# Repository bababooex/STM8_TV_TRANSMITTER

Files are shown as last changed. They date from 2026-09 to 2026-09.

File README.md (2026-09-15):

# **STM8_TV_TRANSMITTER**
My first experiments with bare metal programming on STM8. With SPL from ST I wouldn´t be able to fit whole code in the chip. This replaces rf modulator library for STM8 that I used earlier. I also took alot of inspiration from various websites and forums, so for these have look at credits. RF modulator used accepts analog video and audio inputs and gives RF out power around 82 dBuV max on 75 ohm (2.11 µW/-26.75 dBm). RF amplifier gives the low power signal some boost (~40 dB) to get to mW range (<30 mW). With good antenna this signal should reach atleast few tenths of meters. TV channels are configured for east european analog TV standard frequencies, not american!
> [!WARNING]
> RF modulator, when amplified, breaks RF laws in some countries, like Czechia (ČTÚ limits). I´m not responsible for any interference with public services or radio stations. Analog TV signals are quite wide on the spectrum and also noisy, so be careful!
## **Default pins and connections**
- button pins are adjustable in main.c, display connections in display .header file, software i2c pins in swi2c .header file. I you want to change them, follow the proper definitions (port a as PA and pin 
 as PIN2 for example)
- RF modulator RF out to RF amp input, RF amp output to proper antenna, like uhf folded dipole to give maximum range. Or you can just connect RF modulator output directly to TV and set desired channel or frequency
## **Images**

Device running on channel 21, frequency 471.25 MHz
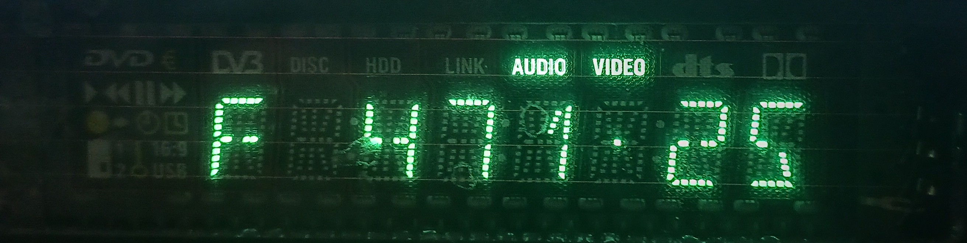
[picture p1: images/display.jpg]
display


RF amplifier - I highly recommend for UHF, because you will get most out of RF modulator. Also, on lower frequencies, there will be harmonics from dividing.
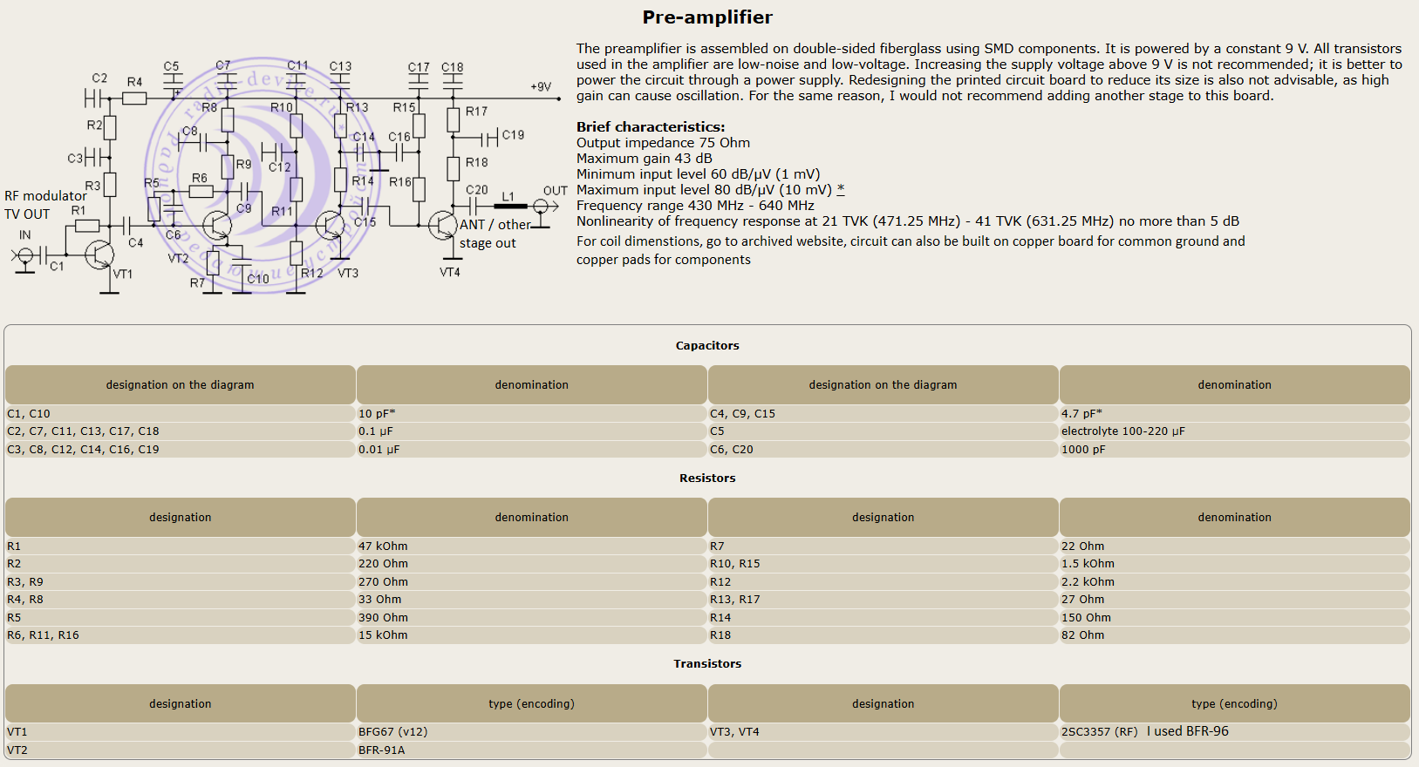
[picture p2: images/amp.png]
amplifier


Basic RF modulator circuit. Either use existing modulator or make it based off the schematic.
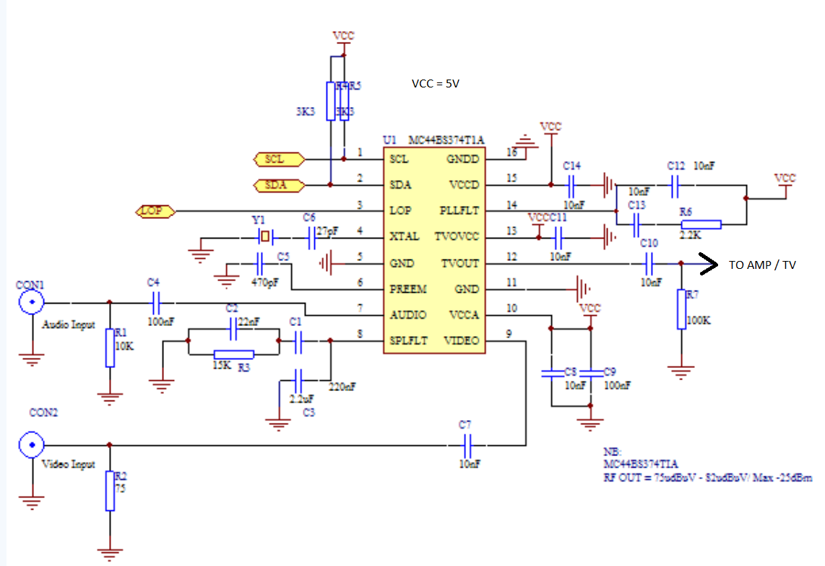
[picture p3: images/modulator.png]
modulator


## **Libraries and header files used**
- My [PT6311/PT6315](https://github.com/bababooex/STM8_PT6311_LIBRARY) library to control the VFD display
- MBS74T1AEF (MC44BS374T1) [RF modulator](https://github.com/tom2238/arduino-mc44bs374t1) library from Arduino, rewritten for STM8 compatibility with AIs help
- [Register tables](https://github.com/jukkas/stm8-sdcc-examples/blob/master/stm8.h) for stm8s103 + with some additions from me
## **Credits**
- Russian forum [VRTP.RU](https://vrtp.ru/) for project inspiration and control + software behavior, my device tries to be similar like described [here](https://vrtp.ru/index.php?act=categories&CODE=article&article=3650)
- @tom2238 for his arduino code
- @jukkas for his register table that I didn´t have to create from scratch

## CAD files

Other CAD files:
RFmod_bare_metal/rfmod_bare_metal.stp

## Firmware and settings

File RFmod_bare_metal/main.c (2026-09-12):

#include "stm8_pt6311.h"
#include "stm8s_delay.h"
#include "mbs74t1aef.h"
#include "stm8s.h"
#include "swi2c.h"

/*
 *  Software controller for MBS74T1AEF with user interface with VFD display (HL-D898W) board from sat. tuner and three buttons.
 *	UP button toggles on/off functions, or moves channel/frequency up, STATUS button changes screen view, DOWN button moves channel/frequency down. 
 *  Device uses internal EEPROM to save user data, if required, otherwise defaults to channel 21 and D/K sound system
 *
 *  tested on stm8s103f3p6 chip
 *  Created on: 12. 9. 2026
 *  Author: Adam Fucik
 *  
 */
 
//macros for buttons
#define UP_BTN_PORT  PC
#define UP_BTN_PIN   PIN4
#define STATUS_BTN_PORT   PC
#define STATUS_BTN_PIN PIN3
#define DOWN_BTN_PORT  PA
#define DOWN_BTN_PIN  PIN3
//readers
#define UP_BTN_READ()      ((PORT(UP_BTN_PORT, IDR) & UP_BTN_PIN) ? 1 : 0)
#define STATUS_BTN_READ()  ((PORT(STATUS_BTN_PORT, IDR) & STATUS_BTN_PIN) ? 1 : 0)
#define DOWN_BTN_READ()    ((PORT(DOWN_BTN_PORT, IDR) & DOWN_BTN_PIN) ? 1 : 0)
// Constants for acceleration
#define DEBOUNCE_MS         10
#define INITIAL_REPEAT_DELAY_MS  500   //autorepeat
#define INITIAL_REPEAT_INTERVAL_MS 450 // first repeat
#define MIN_REPEAT_INTERVAL_MS     5  // fastest repeat
#define ACCEL_FACTOR         4        // repeat divider
//memory start addr
#define EEPROM_START       0x4000
//freq + channel macros
#define RF_FREQ_MIN_KHZ          45000
#define RF_FREQ_MAX_KHZ         880000
#define RF_FREQ_STEP_KHZ           250
//channel frequencies in khz
#define CH21_FREQ_KHZ           471250
#define CH21_LAST_FREQ_KHZ      871250
#define CH6_FREQ_KHZ            175250
#define CH12_FREQ_KHZ           223250
#define CH3_FREQ_KHZ             77250
#define CH5_FREQ_KHZ             93250
#define CH1_FREQ_KHZ             49750
#define CH2_FREQ_KHZ             59250
//all toggleable screens in enum
typedef enum {
		frequency_state=0,
    channel_state,
		sound_state,
		ps_ratio_state,
		tpen_state,
		pwc_state,
		memory_state
} ScreenState;
//sound enum
typedef enum {
    MN_4_5MHZ = 0,
    BG_5_5MHZ,
    I_6_0MHZ,
    DK_6_5MHZ
} RFMod_sound_system;
//last memory conf enum
typedef struct {
    uint32_t frequency;
    uint8_t  ps_ratio;
    uint8_t  tpen;
    uint8_t  pwc;
    uint8_t  sound;
} Data_Memory;
//button speeder
typedef struct {
    uint8_t last_raw;         
    uint8_t stable;            
    uint8_t pressed;          
    uint32_t debounce_start;   
    uint32_t press_start;    
    uint32_t last_repeat;     
    uint16_t repeat_interval;  
} ButtonAccel;
//simple debounce eunm
typedef struct {
    uint8_t last_raw;
    uint8_t stable;
    uint32_t debounce_start;
} ButtonSimple;
//global vars
ScreenState current_screen;
RFModulator mod;
static volatile uint32_t tim4_ms_counter = 0;
//aliases for nonblocking buttons
ButtonAccel up_btn, down_btn;
ButtonSimple status_btn;
//shitter
uint8_t i;
//all data from mod defualts
uint32_t mod_frequency = 471250;
bool ps_ratio = 0;
bool tpen = 0;
bool pwc = 0;
uint8_t channel, last_channel = 21;
RFMod_sound_system sound = DK_6_5MHZ;

bool change_tracker = false;

void button_accel_init(ButtonAccel *btn);
void button_simple_init(ButtonSimple *btn);
uint8_t button_accel_check(uint8_t raw, ButtonAccel *btn);
uint8_t button_simple_check(uint8_t raw, ButtonSimple *btn);

void clock_setup(void);
void tim4_isr_setup(void);
void memory_handler(bool write);//memory saver
//screens - each matches different toggleable modulator configuration
void frequency_screen(void);
void channel_screen(void);
void sound_screen(void);
void ps_ratio_screen(void);
void tpen_screen(void);
void pwc_screen(void);
void memory_screen(void);
//st button checker
void check_st_button(void);
void btn_init(void);
//screen updater
void update_screen(void);

void freq_visuals(uint32_t frequency);
void freq_update_visuals(uint8_t move, uint16_t step_khz);
void channel_update_visuals(uint8_t move);
void channel_recalculate(uint32_t mod_frequency);
void bool_updaters(ScreenState screen);
void sound_system(RFMod_sound_system value);

@far @interrupt void timer4_isr(void)
{
    ++tim4_ms_counter; 
    TIM4_SR &= (uint8_t)(~TIM_SR1_UIF);
}

void main(void)
{
		clock_setup();//init main clock + timer
		tim4_isr_setup();//nonblocking delay
		btn_init();
		button_accel_init(&up_btn);
		button_accel_init(&down_btn);
		button_simple_init(&status_btn);
		pt6311_init(9);
		pt6311_set_display_state(PT6311_DISPLAY_ON);//prevent bugs
		for (i = 1; i < 10; i++)
		{
        pt6311_write_digit(i, 0xFFFFFF); 
				delay_ms(200);
		}
		delay_ms(300);
		pt6311_clear_display();
		pt6311_write_string(1,"TVTXV1-0 ");
		delay_ms(1200);
		pt6311_clear_display();	
		swi2c_init();
		RFModulator_Init(&mod, MC44BS374T1_ADDR);//start with defaults
		memory_handler(0); //load last data
		current_screen = frequency_state;//force current screen
		//force to display data directy to avoid errors
		pt6311_write_string(1,"F");
		freq_visuals(mod_frequency);
		while (1) {
			update_screen();
			check_st_button();
		}
}
void btn_init(void){//init three buttons as pu no it
		PORT(UP_BTN_PORT, DDR) &= ~UP_BTN_PIN;
    PORT(UP_BTN_PORT, CR1) |= UP_BTN_PIN;
    PORT(UP_BTN_PORT, CR2) &= ~UP_BTN_PIN;
		PORT(DOWN_BTN_PORT, DDR) &= ~DOWN_BTN_PIN;
    PORT(DOWN_BTN_PORT, CR1) |= DOWN_BTN_PIN;
    PORT(DOWN_BTN_PORT, CR2) &= ~DOWN_BTN_PIN;
		PORT(STATUS_BTN_PORT, DDR) &= ~STATUS_BTN_PIN;
    PORT(STATUS_BTN_PORT, CR1) |= STATUS_BTN_PIN;
    PORT(STATUS_BTN_PORT, CR2) &= ~STATUS_BTN_PIN;
}
//eeprom memory helpers
static void eeprom_unlock(void)
{
    if (!(FLASH_IAPSR & FLASH_IAPSR_DUL)) {
        FLASH_DUKR = FLASH_DUKR_KEY1;
        FLASH_DUKR = FLASH_DUKR_KEY2;

        while (!(FLASH_IAPSR & FLASH_IAPSR_DUL));
    }
}
static void eeprom_lock(void)
{
    FLASH_IAPSR &= (uint8_t)~FLASH_IAPSR_DUL;
}
static void eeprom_write_byte(uint16_t addr, uint8_t value)
{
    eeprom_unlock();

    *(volatile uint8_t *)addr = value;

    while (!(FLASH_IAPSR & FLASH_IAPSR_EOP));

    eeprom_lock();
}
static uint8_t eeprom_read_byte(uint16_t addr)
{
    return *(volatile uint8_t *)addr;
}
static void eeprom_write(uint16_t addr, const uint8_t *data, uint8_t len)
{
    uint8_t i;

    eeprom_unlock();

    for (i = 0; i < len; i++) {
        *(volatile uint8_t *)addr++ = data[i];

        while (!(FLASH_IAPSR & FLASH_IAPSR_EOP));
    }

    eeprom_lock();
}
static void eeprom_read(uint16_t addr, uint8_t *data, uint8_t len)
{
    uint8_t i;

    for (i = 0; i < len; i++) {
        data[i] = *(volatile uint8_t *)addr++;
    }
}
//memory handling
void memory_handler(bool write) {
	Data_Memory M;
	if (write){
    M.frequency = (uint32_t) mod_frequency;
    M.ps_ratio  = (bool)ps_ratio;
    M.tpen      = (bool)tpen;
    M.pwc       = (bool)pwc;
    M.sound     = (uint8_t)sound;
    eeprom_write(EEPROM_START,
                 (uint8_t *)&M,
                 sizeof(Data_Memory));
	}
	else{
    eeprom_read(EEPROM_START,
                (uint8_t *)&M,
                sizeof(Data_Memory));
		if (M.frequency < RF_FREQ_MIN_KHZ ||//some validation here
        M.frequency > RF_FREQ_MAX_KHZ ||
        M.sound > DK_6_5MHZ) {
				mod_frequency = 471250;
        ps_ratio = 0;
        tpen = 0;
        pwc = 0;
        sound = DK_6_5MHZ;
        RFModulator_SetFrequency(&mod, mod_frequency);
			}
		else{
        mod_frequency = M.frequency;
        ps_ratio = M.ps_ratio;
        tpen     = M.tpen;
        pwc      = M.pwc;
        sound    = (RFMod_sound_system)M.sound;

        RFModulator_SetFrequency(&mod, mod_frequency);
        RFModulator_SetPictureSoundRatio(&mod, ps_ratio);
        RFModulator_SetSoundSubcarrier(&mod, sound);
        RFModulator_SetPeakWhiteClip(&mod, pwc);
        RFModulator_SetTestPattern(&mod, tpen);
    } 
	}
}
static void question_writer(void){//write ?
		pt6311_write_digit(6, 0x1051);
		pt6311_write_digit(7, 0x000000);
}
//last data saver
void memory_screen(void){
	if (!change_tracker){
			pt6311_write_string(1,"SAVE ");
			question_writer();
			change_tracker=true;
		}
    if (button_accel_check(UP_BTN_READ(), &up_btn)) {
        memory_handler(1);
				//indicate
				pt6311_write_string(6,"OK");
				pt6311_write_digit(0, 128);
				delay_ms(300);
				pt6311_write_string(1,"SAVE");
				question_writer();
				pt6311_write_digit(0, 0x000000);
    } 
}
//init button speeder func
void button_accel_init(ButtonAccel *btn) {
    btn->last_raw = 1;
    btn->stable = 1;
    btn->pressed = 0;
    btn->debounce_start = 0;
    btn->press_start = 0;
    btn->last_repeat = 0;
    btn->repeat_interval = INITIAL_REPEAT_INTERVAL_MS;
}
//check speeding
uint8_t button_accel_check(uint8_t raw, ButtonAccel *btn)
{
    uint32_t now = tim4_ms_counter;

    if (raw != btn->last_raw) {
        btn->last_raw = raw;
        btn->debounce_start = now;
    }

    if ((uint32_t)(now - btn->debounce_start) >= DEBOUNCE_MS) {
        btn->stable = raw;
    }

    if (btn->stable == 0 && !btn->pressed) {
        btn->pressed = 1;
        btn->press_start = now;
        btn->last_repeat = now;
        btn->repeat_interval = INITIAL_REPEAT_INTERVAL_MS;
        return 1;
    }

    if (btn->stable == 0 && btn->pressed) {
        if ((uint32_t)(now - btn->press_start) >= INITIAL_REPEAT_DELAY_MS) {

            if ((uint32_t)(now - btn->last_repeat) >= btn->repeat_interval) {
                btn->last_repeat = now;

                if (btn->repeat_interval > MIN_REPEAT_INTERVAL_MS) {
                    btn->repeat_interval =
                        (uint16_t)((btn->repeat_interval * 8) / 10);

                    if (btn->repeat_interval < MIN_REPEAT_INTERVAL_MS) {
                        btn->repeat_interval = MIN_REPEAT_INTERVAL_MS;
                    }
                }

                return 1;
            }
        }
    }

    if (btn->stable == 1 && btn->pressed) {
        btn->pressed = 0;
    }

    return 0;
}

void button_simple_init(ButtonSimple *btn) {
    btn->last_raw = 1;
    btn->stable = 1;
    btn->debounce_start = 0;
}
uint8_t button_simple_check(uint8_t raw, ButtonSimple *btn)
{
    uint32_t now = tim4_ms_counter;

    if (raw != btn->last_raw) {
        btn->last_raw = raw;
        btn->debounce_start = now;
    }

    if ((uint32_t)(now - btn->debounce_start) >= DEBOUNCE_MS) {
        if (btn->stable != raw) {
            btn->stable = raw;

            if (btn->stable == 0) {
                return 1;
            }
        }
    }

    return 0;
}

void clock_setup(void)
	{
		CLK_CKDIVR = 0;
  }
	
void tim4_isr_setup(void) {
    TIM4_CR1 &= ~TIM_CR1_CEN;    
    TIM4_PSCR = 0x07;  
    TIM4_ARR = 124;    
		TIM4_CNTR = 0;
		TIM4_SR &= ~TIM_SR1_UIF;
    TIM4_IER |= TIM_IER_UIE;
    TIM4_CR1 |= TIM_CR1_CEN;
    enableInterrupts();
}
/*//lock indicator, because memory constraints, Im not using it
static void lock_reader(void){
	bool lock;
	lock = !((RFModulator_GetStatus(&mod) >> 0) & 1);
	if (lock){
		pt6311_write_digit(0, 8192);
	}
	else{
		pt6311_write_digit(0, 0x000000);
	}
}
*/
void check_st_button(void) {
        if (button_simple_check(STATUS_BTN_READ(), &status_btn)) {
            current_screen++;
						change_tracker=false;//track static changes, avoid refreshing not needed stuff
            if (current_screen > memory_state) {
                current_screen = frequency_state;
            }
            pt6311_clear_display();	
		}
}

void update_screen(void) {
    switch (current_screen) {
				case frequency_state:
            frequency_screen();
            break;
			
				case channel_state:
            channel_screen();
            break;
						
        case sound_state:
            sound_screen();
            break;
						
        case ps_ratio_state:
            ps_ratio_screen();
            break;
            
        case tpen_state:
            tpen_screen();
            break;
            
        case pwc_state:
            pwc_screen();
            break;
				
				case memory_state:
            memory_screen();
            break;		
						
        default:
            current_screen = frequency_state;
            break;
    }
}

void freq_visuals(uint32_t mod_frequency){//onetime frequency load
	uint16_t frec1;
	int8_t frec2;
	frec1 = (uint16_t)(mod_frequency / 1000);
	frec2 = (uint8_t)((mod_frequency % 1000) / 10);
	
	if (frec1<100){
		pt6311_write_digit(3, 0x000000);
		pt6311_write_int(4,frec1);//mhz
	}
	else{
		pt6311_write_int(3,frec1);//mhz
	}
	if (frec2==0){
		//shitty corrector
		pt6311_write_string(7,"00");//khz
	}
	else{
		pt6311_write_int(7,frec2);//khz
	}
	pt6311_write_digit(6, 0x80);//dec dot
}

void freq_update_visuals(uint8_t move, uint16_t khz_step){//frequency updater
	if (move) {
        if (mod_frequency <= (RF_FREQ_MAX_KHZ - khz_step)) {
            mod_frequency += khz_step;
        }
	} else {
        if (mod_frequency >= (RF_FREQ_MIN_KHZ + khz_step)) {
            mod_frequency -= khz_step;
        }
	}
		
	freq_visuals(mod_frequency);			
	RFModulator_SetFrequency(&mod, mod_frequency);
}

void frequency_screen(void)//up or down 250 khz
{
		if (!change_tracker){
			pt6311_write_string(1,"F");
			freq_visuals(mod_frequency);
			change_tracker=true;
		}
    if (button_accel_check(UP_BTN_READ(), &up_btn)) {
        freq_update_visuals(1, RF_FREQ_STEP_KHZ);
    } else if (button_accel_check(DOWN_BTN_READ(), &down_btn)) {
        freq_update_visuals(0, RF_FREQ_STEP_KHZ);
    }
}

void channel_update_visuals(uint8_t move){
		if (move){
			if (channel < 12) {
					channel++;
				} else if (channel == 12) {
						channel = 21;
        } else if (channel < 71) {
            channel++;
        }
		}
		else{
			if (channel > 21) {
							channel--;
        } else if (channel == 21) {
            channel = 12;
        } else if (channel > 1) {
            channel--;
        }
		}
		//recalculation from library used in here, avoids rfmodulator set channel function
		if (channel >= 21) {
        mod_frequency =
            CH21_FREQ_KHZ + ((uint32_t)(channel - 21) * 8000);
    } else if (channel >= 6) {
        mod_frequency =
            CH6_FREQ_KHZ + ((uint32_t)(channel - 6) * 8000);
    } else if (channel >= 3) {
        mod_frequency =
            CH3_FREQ_KHZ + ((uint32_t)(channel - 3) * 8000);
    } else {
        mod_frequency =
            CH1_FREQ_KHZ + ((uint32_t)(channel - 1) * 9500);
    }
		if (channel<10){
			pt6311_write_digit(7, 0x000000);
			pt6311_write_int(6, channel);
		}
		else{
			pt6311_write_int(6, channel);
		}
		RFModulator_SetFrequency(&mod, mod_frequency);
}
void channel_recalculate(uint32_t mod_frequency) {
		if (mod_frequency >= CH21_FREQ_KHZ && mod_frequency <= CH21_LAST_FREQ_KHZ) {
        channel = (uint8_t)(21 + ((mod_frequency - CH21_FREQ_KHZ) / 8000));
        if (channel > 71) {
            channel = 71;
        }
    }
    else if (mod_frequency >= CH6_FREQ_KHZ && mod_frequency <= CH12_FREQ_KHZ) {
        channel = (uint8_t)(6 + ((mod_frequency - CH6_FREQ_KHZ) / 8000));
        if (channel > 12) {
            channel = 12;
        }
    }
    else if (mod_frequency >= CH3_FREQ_KHZ && mod_frequency <= CH5_FREQ_KHZ) {
        channel = (uint8_t)(3 + ((mod_frequency - CH3_FREQ_KHZ) / 8000));
        if (channel > 5) {
            channel = 5;
        }
    }
    else if (mod_frequency >= CH1_FREQ_KHZ && mod_frequency <= CH2_FREQ_KHZ) {
        channel = (uint8_t)(1 + ((mod_frequency - CH1_FREQ_KHZ) / 9500));
        if (channel > 2) {
            channel = 2;
        }
    }
    else {
        channel = last_channel;//if user goes out of channel range display last valid
    }
		last_channel=channel;//save last valid channel matching exact frequency
    if (channel<10){
			pt6311_write_digit(7, 0x000000);
			pt6311_write_int(6, channel);
		}
		else{
			pt6311_write_int(6, channel);
		}
}
void channel_screen(void){
		if (!change_tracker){
				pt6311_write_string(1,"CHAN");
				channel_recalculate(mod_frequency);
				change_tracker=true;
		}
		if (button_accel_check(UP_BTN_READ(), &up_btn)){
					channel_update_visuals(1);
		} else if (button_accel_check(DOWN_BTN_READ(), &down_btn))  {
					channel_update_visuals(0);					
		} 
}

void bool_updaters(ScreenState screen){//bool updaters 
		if (screen == ps_ratio_state) {
			if (ps_ratio){
					pt6311_write_string(5,"16dB");
					RFModulator_SetPictureSoundRatio(&mod, MC44BS374T1_PS_16);
					pt6311_write_digit(0, 16384);
				}
				else{
					pt6311_write_string(5,"12dB");
					RFModulator_SetPictureSoundRatio(&mod, MC44BS374T1_PS_12);
					pt6311_write_digit(0, 0x000000);
				}
			
    } 
    else if (screen == tpen_state){
        if (tpen){
					pt6311_write_string(6,"ON ");
					RFModulator_SetTestPattern(&mod, MC44BS374T1_TPEN_ON);
					pt6311_write_digit(0, 64);
				}
				else{
					pt6311_write_string(6,"OFF");
					RFModulator_SetTestPattern(&mod, MC44BS374T1_TPEN_OFF);
					pt6311_write_digit(0, 0x000000);
				}
    } 
    else if (screen == pwc_state) {
			if (pwc){
					pt6311_write_string(6,"OFF");
					RFModulator_SetPeakWhiteClip(&mod, MC44BS374T1_PWC_OFF);
					pt6311_write_digit(0, 1024);
				}
				else{
					pt6311_write_string(6,"ON ");
					RFModulator_SetPeakWhiteClip(&mod,MC44BS374T1_PWC_ON);
					pt6311_write_digit(0, 0x000000);
				}
    }
}

void tpen_screen(void)//test pattern toggle
{
		if (!change_tracker){
			pt6311_write_string(1,"TPEN");
			bool_updaters(current_screen);
			change_tracker=true;
		}
		if (button_accel_check(UP_BTN_READ(), &up_btn)) {
					tpen = !tpen;
					bool_updaters(current_screen);
		} 
}

void pwc_screen(void)
{
		if (!change_tracker){
			pt6311_write_string(1,"PWC");
			bool_updaters(current_screen);
			change_tracker=true;
		}
		if (button_accel_check(UP_BTN_READ(), &up_btn)) {
					pwc = !pwc;
					bool_updaters(current_screen);
		} 
}

void ps_ratio_screen(void)
{
		if (!change_tracker){
			pt6311_write_string(1,"P-S");
			bool_updaters(current_screen);
			change_tracker=true;
		}
		if (button_accel_check(UP_BTN_READ(), &up_btn)) {
					ps_ratio = !ps_ratio;
					bool_updaters(current_screen);
		} 
}

void sound_screen(void)
{
    if (!change_tracker) {
        pt6311_write_string(1, "SYS");
        sound_system(sound);
        change_tracker = true;
    }

    if (button_accel_check(UP_BTN_READ(), &up_btn)) {
        if (sound >= DK_6_5MHZ) {
            sound = MN_4_5MHZ;
        } else {
            sound++;
        }
        sound_system(sound);
    }
    else if (button_accel_check(DOWN_BTN_READ(), &down_btn)) {
        if (sound == MN_4_5MHZ) {
            sound = DK_6_5MHZ;
        } else {
            sound--;
        }
        sound_system(sound);
    }
}
void sound_system(RFMod_sound_system value)
{
    if (value > DK_6_5MHZ) {
        value = MN_4_5MHZ;
    }
    sound = value;
    switch (sound) {
    case MN_4_5MHZ:
        pt6311_write_string(5, "M/N ");
        RFModulator_SetSoundSubcarrier(&mod, MC44BS374T1_SFD_45);
        break;

    case BG_5_5MHZ:
        pt6311_write_string(5, "B/G ");
        RFModulator_SetSoundSubcarrier(&mod, MC44BS374T1_SFD_55);
        break;

    case I_6_0MHZ:
        pt6311_write_string(5, "I   ");
        RFModulator_SetSoundSubcarrier(&mod, MC44BS374T1_SFD_60);
        break;

    case DK_6_5MHZ:
        pt6311_write_string(5, "D/K ");
        RFModulator_SetSoundSubcarrier(&mod, MC44BS374T1_SFD_65);
        break;
    }
}
@svlreg @far @interrupt void reset_handler(void)//skip stext
{
    //go straight to main
    main();
}

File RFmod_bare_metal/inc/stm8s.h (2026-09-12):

// Taken from https://github.com/jukkas/stm8-sdcc-examples/blob/master/stm8.h

/*
 * Register definitions for STM8S103 (and STM8S003)
 * Still incomplete.
 */
#ifndef _STM8_H
#define _STM8_H

#include <stdlib.h>
#include <stdbool.h>
#include <stdint.h>
#define RESET 0
/* Handy macros for GPIO */
#define CONCAT(a, b)    a##_##b
#define PORT(a, b)      CONCAT(a , b)
#define SWAP(a, b)		{uint16_t temp; temp = a; a = b; b = temp;}

#define PIN0    (1 << 0)
#define PIN1    (1 << 1)
#define PIN2    (1 << 2)
#define PIN3    (1 << 3)
#define PIN4    (1 << 4)
#define PIN5    (1 << 5)
#define PIN6    (1 << 6)
#define PIN7    (1 << 7)

/* Register addresses */

/* Clock */
#define CLK_CKDIVR	*(volatile unsigned char *)0x50C6

/* GPIO */
#define PA_ODR *(volatile unsigned char *)0x5000
#define PA_IDR *(volatile unsigned char *)0x5001
#define PA_DDR *(volatile unsigned char *)0x5002
#define PA_CR1 *(volatile unsigned char *)0x5003
#define PA_CR2 *(volatile unsigned char *)0x5004

#define PB_ODR *(volatile unsigned char *)0x5005
#define PB_IDR *(volatile unsigned char *)0x5006
#define PB_DDR *(volatile unsigned char *)0x5007
#define PB_CR1 *(volatile unsigned char *)0x5008
#define PB_CR2 *(volatile unsigned char *)0x5009

#define PC_ODR *(volatile unsigned char *)0x500A
#define PC_IDR *(volatile unsigned char *)0x500B
#define PC_DDR *(volatile unsigned char *)0x500C
#define PC_CR1 *(volatile unsigned char *)0x500D
#define PC_CR2 *(volatile unsigned char *)0x500E

#define PD_ODR *(volatile unsigned char *)0x500F
#define PD_IDR *(volatile unsigned char *)0x5010
#define PD_DDR *(volatile unsigned char *)0x5011
#define PD_CR1 *(volatile unsigned char *)0x5012
#define PD_CR2 *(volatile unsigned char *)0x5013

/* UART */
#define UART1_SR *(volatile unsigned char *)0x5230
#define UART1_DR *(volatile unsigned char *)0x5231
#define UART1_BRR1 *(volatile unsigned char *)0x5232
#define UART1_BRR2 *(volatile unsigned char *)0x5233
#define UART1_CR1 *(volatile unsigned char *)0x5234
#define UART1_CR2 *(volatile unsigned char *)0x5235
#define UART1_CR3 *(volatile unsigned char *)0x5236
#define UART1_CR4 *(volatile unsigned char *)0x5237
#define UART1_CR5 *(volatile unsigned char *)0x5238
#define UART1_GTR *(volatile unsigned char *)0x5239
#define UART1_PSCR *(volatile unsigned char *)0x523A

#define UART_SR_TXE (1 << 7)
#define UART_SR_TC (1 << 6)
#define UART_SR_RXNE (1 << 5)
#define UART_SR_IDLE (1 << 4)
#define UART_SR_OR (1 << 3)
#define UART_SR_NF (1 << 2)
#define UART_SR_FE (1 << 1)
#define UART_SR_PE (1 << 0)

#define UART_CR1_R8 (1 << 7)
#define UART_CR1_T8 (1 << 6)
#define UART_CR1_UARTD (1 << 5)
#define UART_CR1_M (1 << 4)
#define UART_CR1_WAKE (1 << 3)
#define UART_CR1_PCEN (1 << 2)
#define UART_CR1_PS (1 << 1)
#define UART_CR1_PIEN (1 << 0)

#define UART_CR2_TIEN (1 << 7)
#define UART_CR2_TCIEN (1 << 6)
#define UART_CR2_RIEN (1 << 5)
#define UART_CR2_ILIEN (1 << 4)
#define UART_CR2_TEN (1 << 3)
#define UART_CR2_REN (1 << 2)
#define UART_CR2_RWU (1 << 1)
#define UART_CR2_SBK (1 << 0)

#define UART_CR3_LINEN (1 << 6)
#define UART_CR3_STOP2 (1 << 5)
#define UART_CR3_STOP1 (1 << 4)
#define UART_CR3_CLKEN (1 << 3)
#define UART_CR3_CPOL (1 << 2)
#define UART_CR3_CPHA (1 << 1)
#define UART_CR3_LBCL (1 << 0)

//flash because it is needed in my code
#define FLASH_CR1 *(volatile unsigned char *)0x505A
#define FLASH_CR2 *(volatile unsigned char *)0x505B
#define FLASH_NCR2 *(volatile unsigned char *)0x505C
#define FLASH_FPR *(volatile unsigned char *)0x505D
#define FLASH_NFPR *(volatile unsigned char *)0x505E
#define FLASH_IAPSR *(volatile unsigned char *)0x505F
#define FLASH_PUKR *(volatile unsigned char *)0x5062
#define FLASH_DUKR *(volatile unsigned char *)0x5064

#define FLASH_IAPSR_DUL  (1 << 3)
#define FLASH_IAPSR_EOP  (1 << 2)

#define FLASH_DUKR_KEY1  0xAE
#define FLASH_DUKR_KEY2  0x56

/* Timers */
#define TIM1_CR1 *(volatile unsigned char *)0x5250
#define TIM1_CR2 *(volatile unsigned char *)0x5251
#define TIM1_SMCR *(volatile unsigned char *)0x5252
#define TIM1_ETR *(volatile unsigned char *)0x5253
#define TIM1_IER *(volatile unsigned char *)0x5254
#define TIM1_SR1 *(volatile unsigned char *)0x5255
#define TIM1_SR2 *(volatile unsigned char *)0x5256
#define TIM1_EGR *(volatile unsigned char *)0x5257
#define TIM1_CCMR1 *(volatile unsigned char *)0x5258
#define TIM1_CCMR2 *(volatile unsigned char *)0x5259
#define TIM1_CCMR3 *(volatile unsigned char *)0x525A
#define TIM1_CCMR4 *(volatile unsigned char *)0x525B
#define TIM1_CCER1 *(volatile unsigned char *)0x525C
#define TIM1_CCER2 *(volatile unsigned char *)0x525D
#define TIM1_CNTRH *(volatile unsigned char *)0x525E
#define TIM1_CNTRL *(volatile unsigned char *)0x525F
#define TIM1_PSCRH *(volatile unsigned char *)0x5260
#define TIM1_PSCRL *(volatile unsigned char *)0x5261
#define TIM1_ARRH *(volatile unsigned char *)0x5262
#define TIM1_ARRL *(volatile unsigned char *)0x5263
#define TIM1_RCR *(volatile unsigned char *)0x5264
#define TIM1_CCR1H *(volatile unsigned char *)0x5265
#define TIM1_CCR1L *(volatile unsigned char *)0x5266
#define TIM1_CCR2H *(volatile unsigned char *)0x5267
#define TIM1_CCR2L *(volatile unsigned char *)0x5268
#define TIM1_CCR3H *(volatile unsigned char *)0x5269
#define TIM1_CCR3L *(volatile unsigned char *)0x526A
#define TIM1_CCR4H *(volatile unsigned char *)0x526B
#define TIM1_CCR4L *(volatile unsigned char *)0x526C
#define TIM1_BKR *(volatile unsigned char *)0x526D
#define TIM1_DTR *(volatile unsigned char *)0x526E
#define TIM1_OISR *(volatile unsigned char *)0x526F

/* Note these are for STM8S103 and STM8S003
   STM8S105,104/207/208 are different */
#define TIM2_CR1 *(volatile unsigned char *)0x5300
#define TIM2_CR2 *(volatile unsigned char *)0x5301
#define TIM2_SMCR *(volatile unsigned char *)0x5302
#define TIM2_IER *(volatile unsigned char *)0x5303
#define TIM2_SR1 *(volatile unsigned char *)0x5304
#define TIM2_SR2 *(volatile unsigned char *)0x5305
#define TIM2_EGR *(volatile unsigned char *)0x5306
#define TIM2_CCMR1 *(volatile unsigned char *)0x5307
#define TIM2_CCMR2 *(volatile unsigned char *)0x5308
#define TIM2_CCMR3 *(volatile unsigned char *)0x5309
#define TIM2_CCER1 *(volatile unsigned char *)0x530A
#define TIM2_CCER2 *(volatile unsigned char *)0x530B
#define TIM2_CNTRH *(volatile unsigned char *)0x530C
#define TIM2_CNTRL *(volatile unsigned char *)0x530D
#define TIM2_PSCR *(volatile unsigned char *)0x530E
#define TIM2_ARRH *(volatile unsigned char *)0x530F
#define TIM2_ARRL *(volatile unsigned char *)0x5310
#define TIM2_CCR1H *(volatile unsigned char *)0x5311
#define TIM2_CCR1L *(volatile unsigned char *)0x5312
#define TIM2_CCR2H *(volatile unsigned char *)0x5313
#define TIM2_CCR2L *(volatile unsigned char *)0x5314
#define TIM2_CCR3H *(volatile unsigned char *)0x5315
#define TIM2_CCR3L *(volatile unsigned char *)0x5316
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
